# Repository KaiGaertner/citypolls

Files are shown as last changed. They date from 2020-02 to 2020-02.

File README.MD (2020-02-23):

# Project: Help yourself city

Creating a real life usable voting plattform for local issues. Based on a Raspberry Pi Zero WH, an UMTS module, a powerbank and self made casing out of acryl, it can be put nearly anywhere to vote on a given topic by up- or downvoting.

## Server implemenation
The project uses a simple MySQL database to store the votes over a predefined period of time and can present them via a website. A running prototype could be found at: cit

## UrbanAnt

### Casing
The casing consists of laser cut acryl and 3D printed parts, some buttons, cables and LEDs for the interior. It provides enough space for the Raspberry Pi Zero WH, the UMTS module and a battery.
The case consists of laser cut and 3D-printed parts. The necessary files are included in the folders named correspondingly. 

## Programming
The control programm is written for Python 3 running on Raspbian Buster on the Rasperry Pi. All functionalities can be found in the *box.py* which runs as a service after powering up the device.
The votes are stored locally in a sqlite database and can be commited to the MySQL server in e predefined interval. The only additional dependencies for the programm are the [mysql-connector-python](https://pypi.org/project/mysql-connector-python/) package and [RPi.GPIO](https://pypi.org/project/RPi.GPIO/) which can be installed using:
```bash
pip3 install mysql-connector-python RPi.GPIO
```
For the voting a delay can be set to avoid abusive usage by voting rapidly.

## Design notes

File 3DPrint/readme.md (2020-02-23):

In this folder you can find all the 3D-printed parts for the UrbanAnt device. 
Upvote and Downvote buttons are the same, just be careful when mounting them.

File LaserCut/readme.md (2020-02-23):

In this folder you can find all the lasercut parts for the UrbanAnt device. Every part is stored in a separate pdf file. 
The files are A4-sized, so if you want to use some other technique instead of lasercutting, you can just print them out with a regular printer.

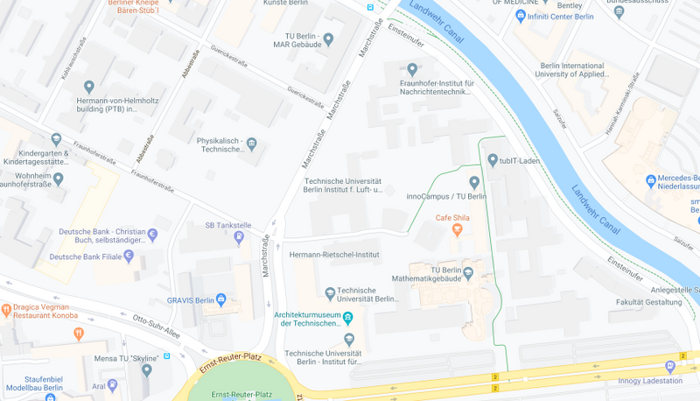
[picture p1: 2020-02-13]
website/images/try-p-800.png

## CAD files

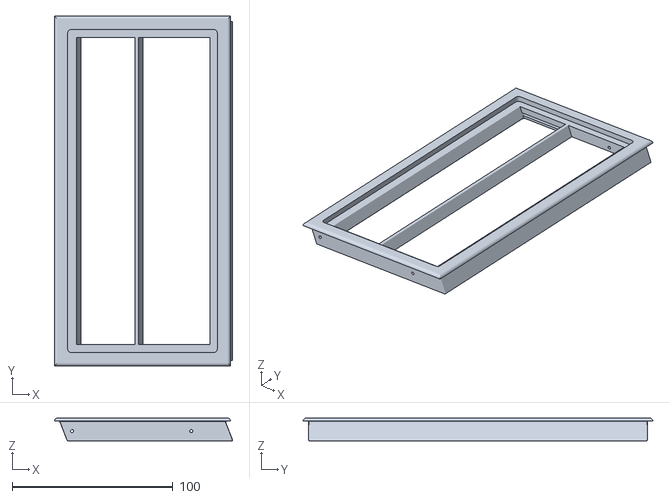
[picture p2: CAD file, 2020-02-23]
3DPrint/Frame_1pc.stl
111.0 x 218.0 x 14.3

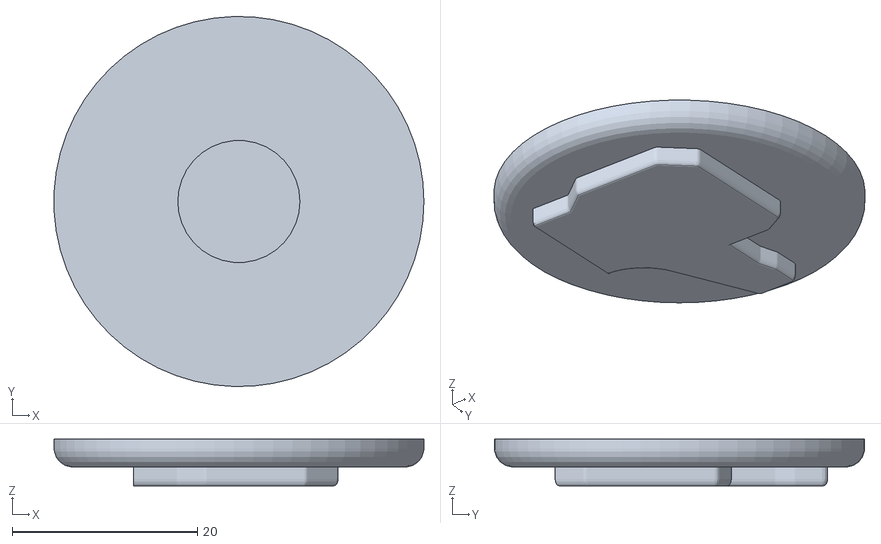
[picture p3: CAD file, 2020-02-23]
3DPrint/VoteButton_2pcs.stl
40.0 x 40.0 x 5.04

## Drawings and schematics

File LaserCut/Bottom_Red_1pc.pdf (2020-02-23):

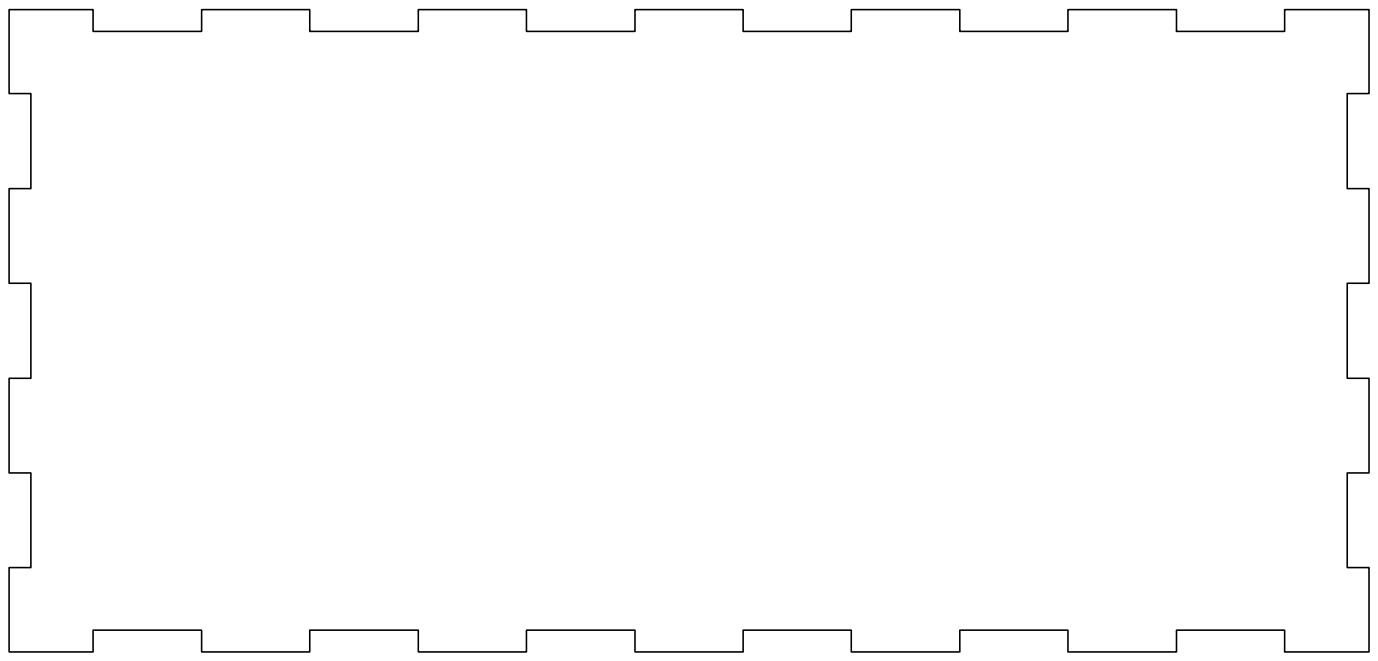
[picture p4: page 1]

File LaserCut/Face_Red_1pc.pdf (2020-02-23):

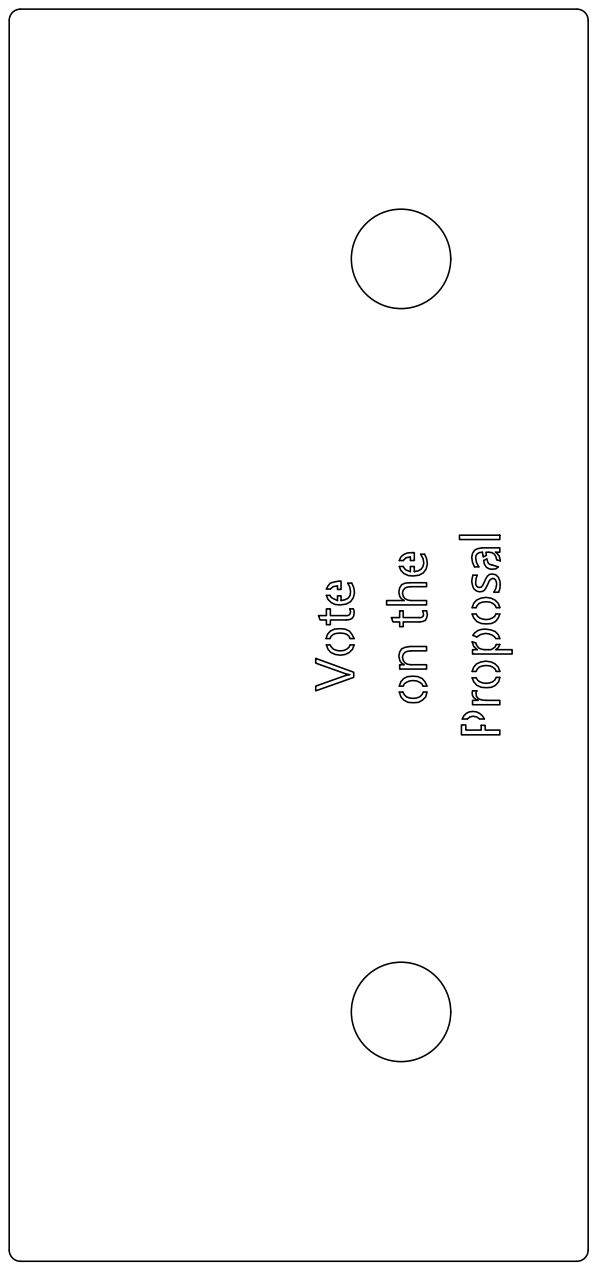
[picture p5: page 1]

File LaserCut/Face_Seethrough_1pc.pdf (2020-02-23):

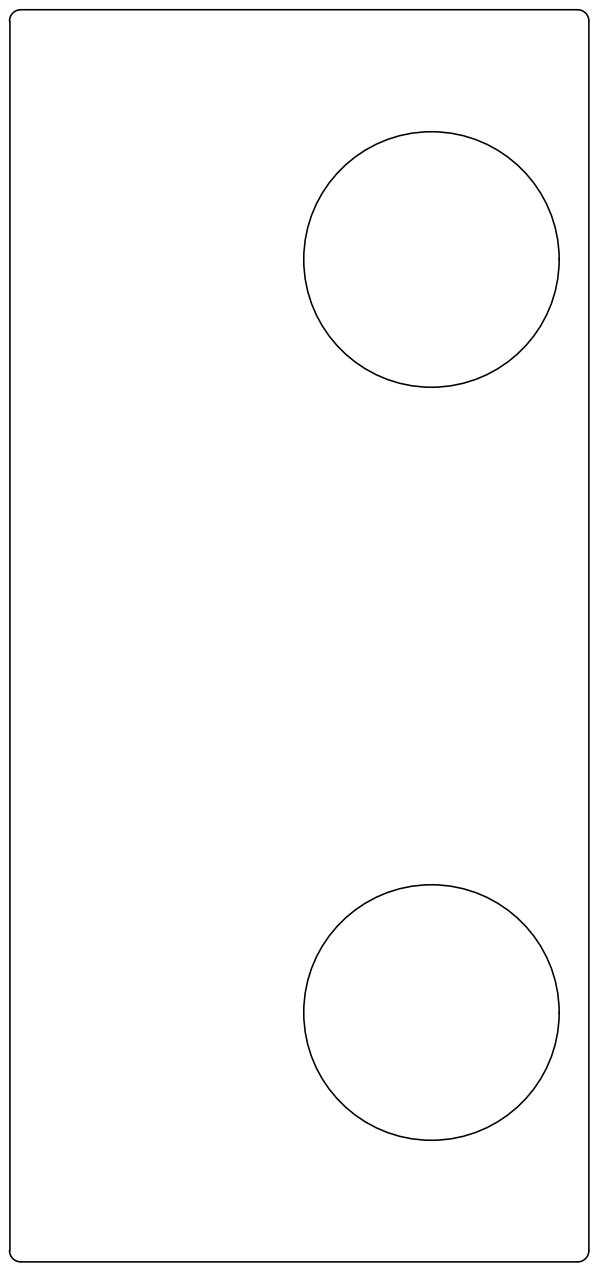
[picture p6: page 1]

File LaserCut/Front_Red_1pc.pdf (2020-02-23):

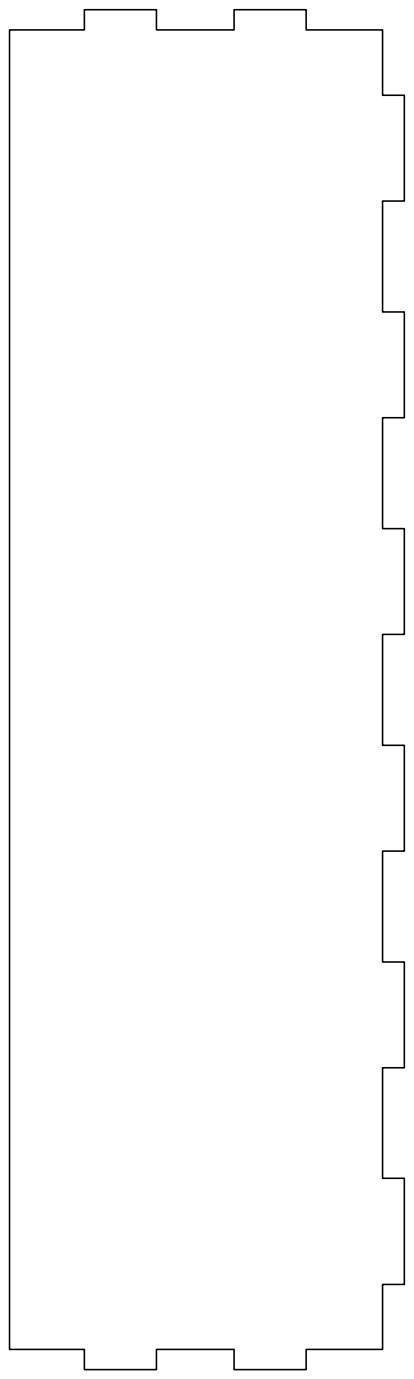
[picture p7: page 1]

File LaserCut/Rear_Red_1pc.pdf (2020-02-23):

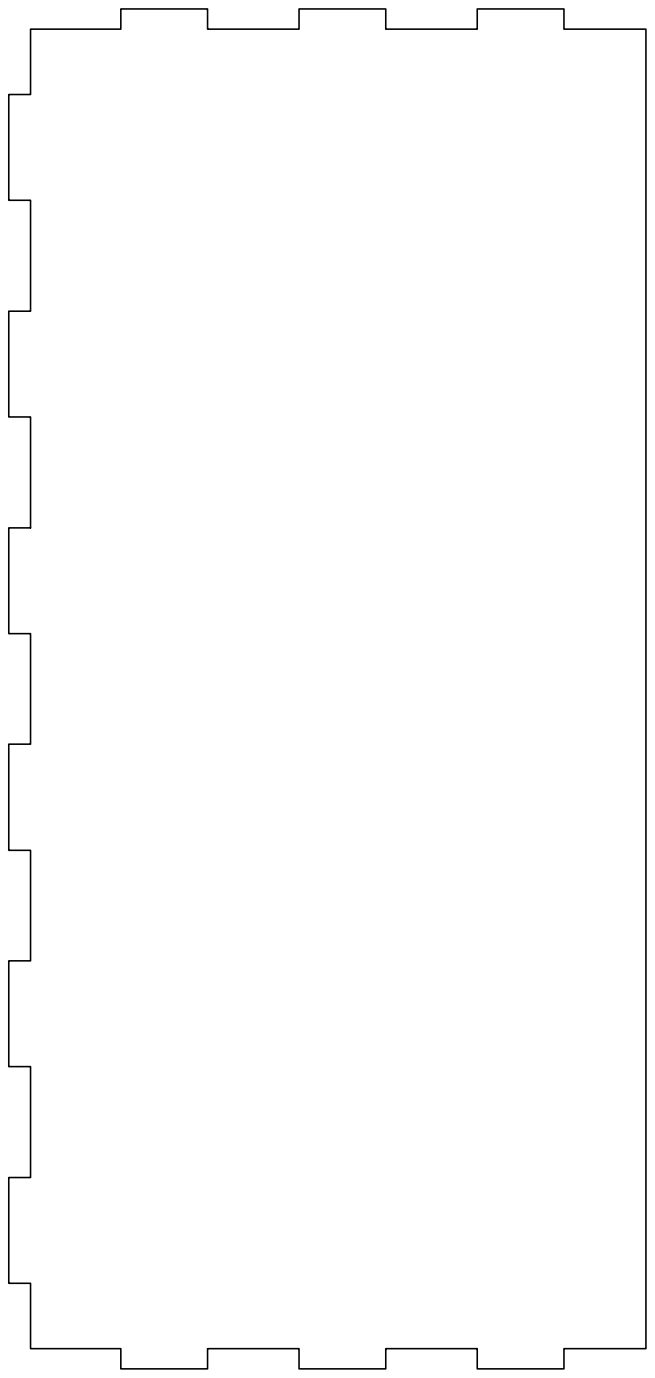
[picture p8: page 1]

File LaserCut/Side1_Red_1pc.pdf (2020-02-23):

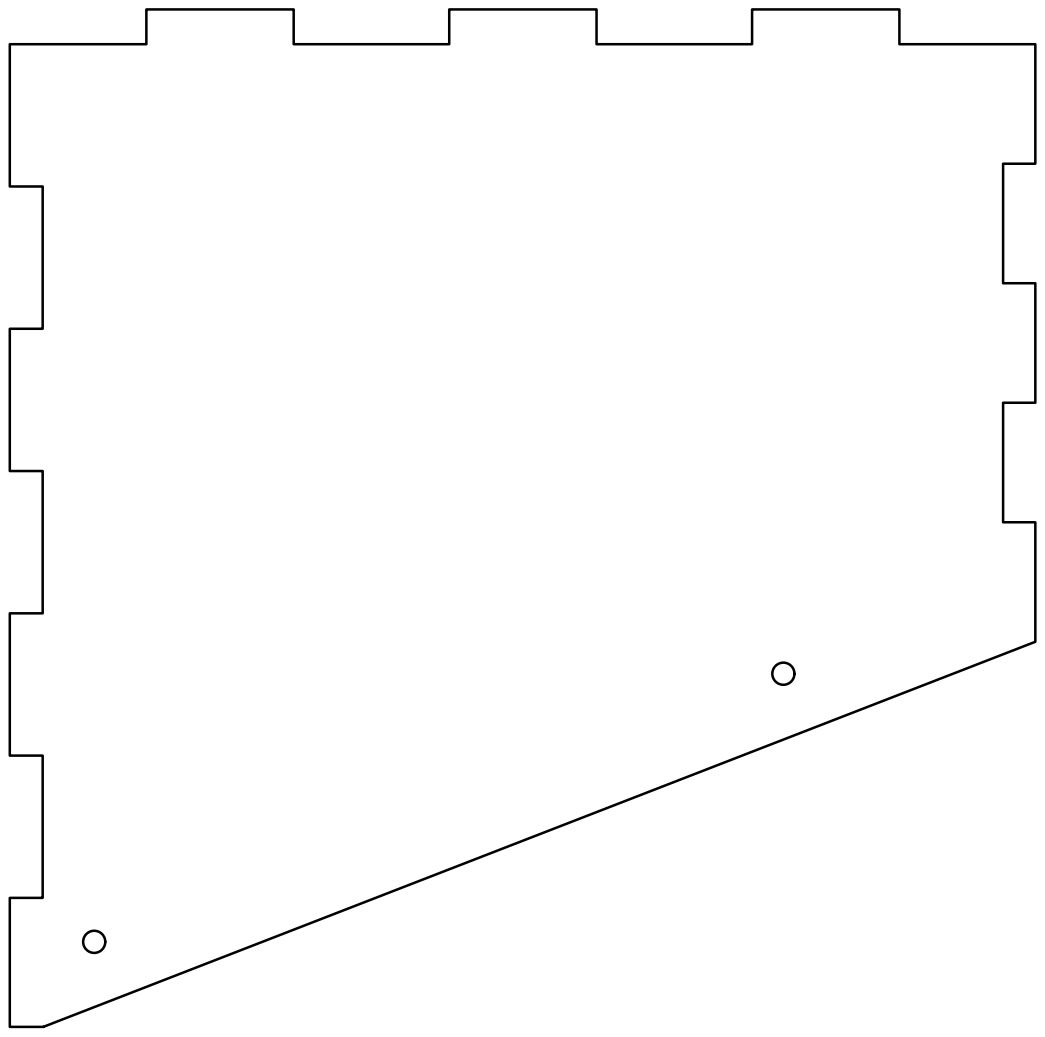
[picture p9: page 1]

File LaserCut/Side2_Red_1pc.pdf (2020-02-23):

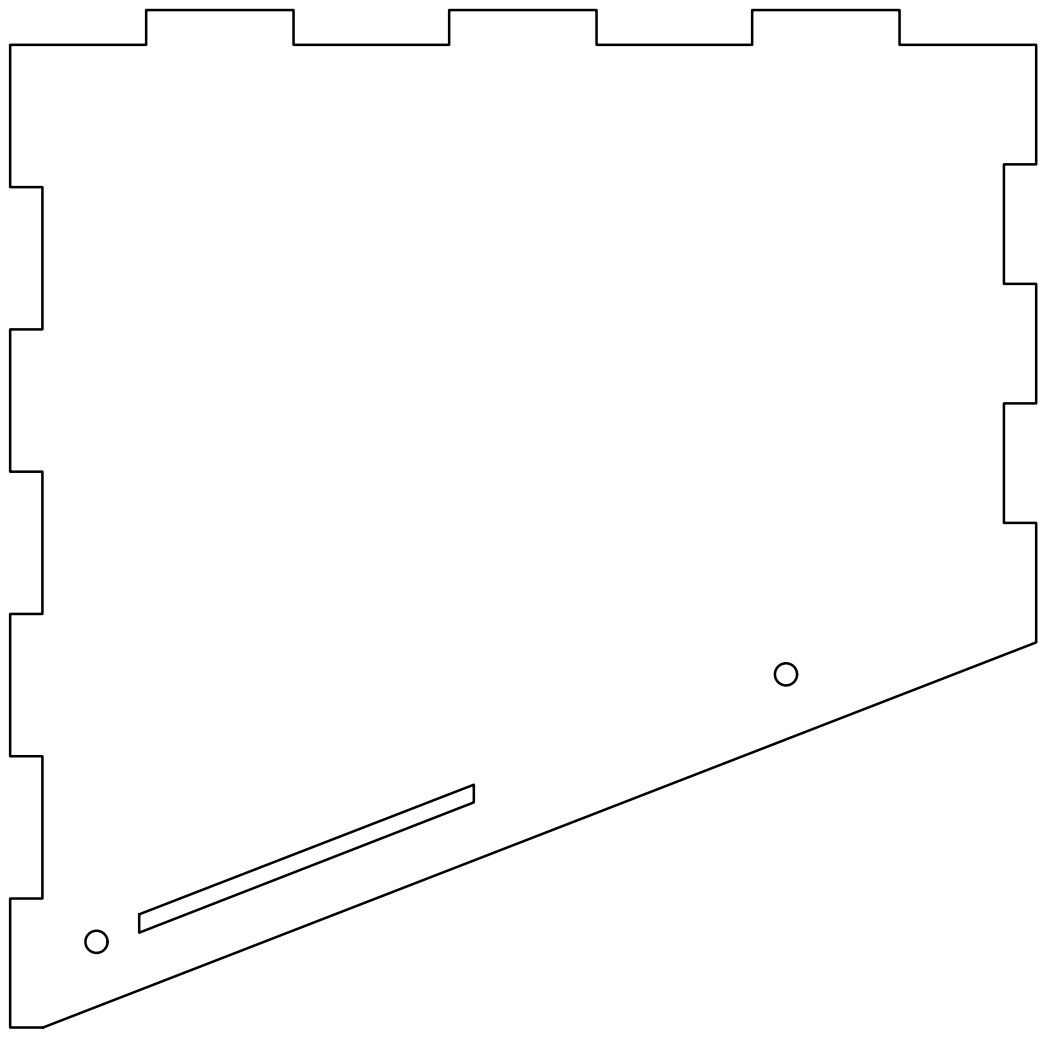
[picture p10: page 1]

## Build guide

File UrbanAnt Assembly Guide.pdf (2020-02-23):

UrbanAnt Assembly Guide

### 1. Gluing the box

Parts needed:
Bottom_Red
Front_Red
Rear_Red
Side1_Red
Side2_Red

Additional material:
Paper tape
Epoxy glue

Instructions:
Put the involved parts together. Use paper tape from the outside to make it stay steadily. Apply (two-component epoxy resin) glue from the inside along the gaps. After the glue has cured, the paper tape can be removed.

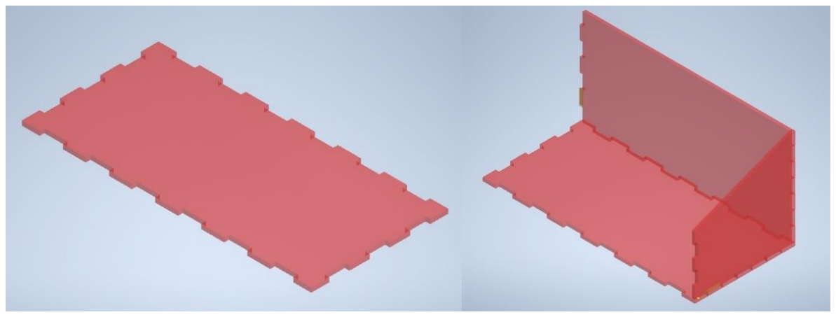
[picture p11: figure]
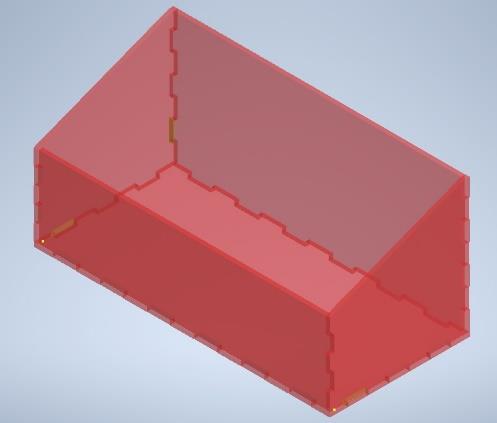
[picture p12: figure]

### 2. Adding brass inserts

Parts needed:
Frame

Additional material and tools: Drill 2.5-2.7mm
Soldering iron
M2 Brass inserts x4

Instructions:
Predrill all four holes on the sides of the frame. Insert the brass inserts using soldering iron.

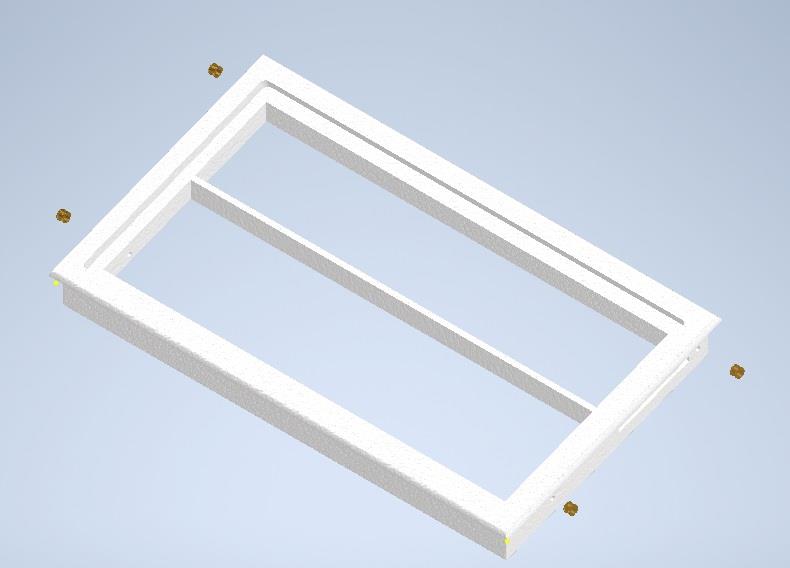
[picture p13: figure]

### 3. Adding the covers

Parts needed:
Frame
Face_Red

Additional material and tools: Epoxy glue

Instructions:
Place and glue the face plate into the frame.

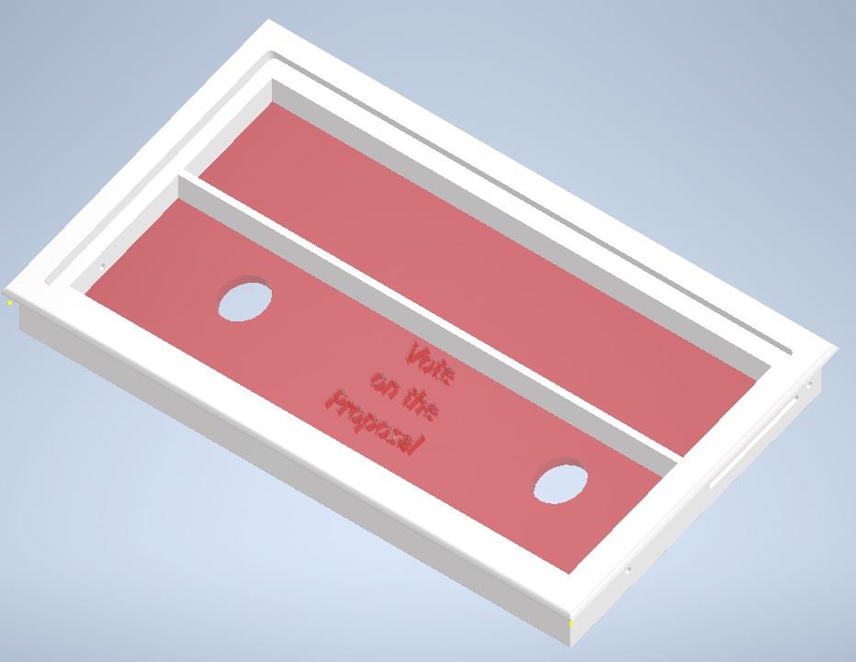
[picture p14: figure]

### 4. Gluing the buttons

Parts needed:
Non-latching buttons x2
VoteButton x2

Additional material and tools: Epoxy glue

Instructions:
Glue the 3D-printed button covers on the buttons. You might need to press them together until the glue cures.

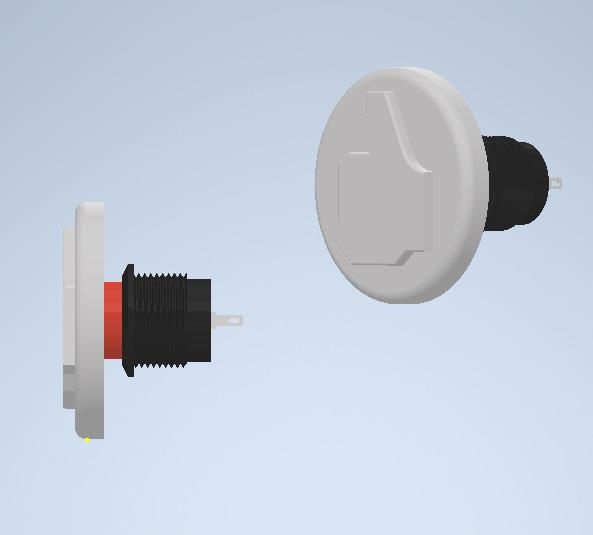
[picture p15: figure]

### 5. Putting UrbanAnt together

Parts needed:
The previous assemblies
Internal electronics assembled based on the GitHub Wiki Front_Seethrough

Additional material and tools:
Epoxy glue
M2 screws x4

Instructions:
Place and mount the buttons. Glue the see-through face on the box, and sink the face assembly into the box. You can secure it with the four screws from the sides. A paper with the message can be added using the slot on the side of the box.

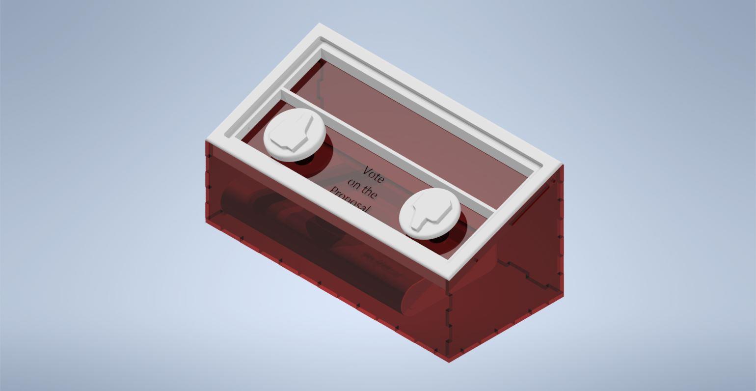
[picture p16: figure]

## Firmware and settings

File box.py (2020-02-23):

import sqlite3, random, time
import mysql.connector
import RPi.GPIO as GPIO
from sqlite3 import Error
import threading


box_id = 1
vote_id = 2

### local counting
def count_vote(conn, vote):
	try:
		c = conn.cursor()
		if vote:
			c.execute(""" UPDATE polls SET yes = yes + 1 WHERE poll_id=""" + str(vote_id))
		else:
			c.execute(""" UPDATE polls SET no = no + 1 WHERE poll_id="""+str(vote_id))
		c.execute(""" UPDATE polls SET last_update = datetime('now') """)
	except Error as e:
		print(e)
	finally:
		conn.commit()


def init_vote(conn):
	c = conn.cursor()
	try:
		c.execute(" INSERT INTO polls (box_id, poll_id, yes, no, last_update) VALUES( " + str(box_id)+"," + str(vote_id)+",0,0,datetime('now')); ")
	except Error as e:
		print(e)

def connect_db():

	""" create a database connection to a SQLite database """
	conn = None
	try:
		conn = sqlite3.connect('local_polls.db')
		try:
			c = conn.cursor()
			c.execute(""" CREATE TABLE IF NOT EXISTS polls (
											box_id integer, poll_id integer PRIMARY KEY,
											yes integer, no integer, last_update datetime
										); """)
			#init_vote(c)
		except Error as e:
			print(e)

	except Error as e:
		print(e)
	finally:
		if conn:
			conn.commit()
			#conn.close()
			return conn




# remote counting
def get_votes():
	""" create a database connection to a SQLite database """
	conn = None
	results = []
	try:
		conn = sqlite3.connect('local_polls.db')
		c = conn.cursor()
		try:
			c.execute(""" SELECT yes, no FROM polls WHERE box_id="""+str(box_id)+""" AND poll_id="""+str(vote_id))
			for row in c.fetchall():
				results.append(row[0])
				results.append(row[1])
				print ("GET VOTES: [BOX-ID]: " + str(box_id) + " [VOTE-ID]: "+ str(vote_id)+" [YES]: "+ str(row[0])+" [NO]: "+str(row[1]))

		except Error as e:
			print(e)

	except Error as e:
		print(e)
	finally:
		if conn:
			conn.close()
	return results


def push_votes(votes):
	if len(votes) > 0:
		try:
			cnx = mysql.connector.connect(user='citypolls', password='Hml8h30#',
										  host='kaigaertner.de',port=3306,
										  database='citypolls')
			mycursor = cnx.cursor()
			sql = " INSERT INTO boxes (boxid, pollid, yes, no, creation) VALUES (%s, %s, %s, %s, NOW()) "
			val = (box_id,vote_id,votes[0], votes[1])
			mycursor.execute(sql, val)
			cnx.commit()
			print(mycursor.rowcount, "record inserted.")
		except mysql.connector.Error as err:
			if err.errno == errorcode.ER_ACCESS_DENIED_ERROR:
				print("Something is wrong with your user name or password")
			elif err.errno == errorcode.ER_BAD_DB_ERROR:
				print("Database does not exist")
			else:
				print(err)
		else:
			cnx.close()

def sync_votes():
	votes = []
	votes = get_votes()
	push_votes(votes)


### main programm ###

# database connection
conn = connect_db()

#button = random.choice((True, False))
#count_vote(conn, button)
#c = conn.cursor()
#get_votes(c)
init_vote(conn)

GPIO.setwarnings(False) # Ignore warning for now
GPIO.setmode(GPIO.BOARD) # Use physical pin numbering
GPIO.setup(10, GPIO.IN, pull_up_down=GPIO.PUD_DOWN) # Set pin 10 to be an input pin and set initial value to be pulle$
GPIO.setup(12, GPIO.IN, pull_up_down=GPIO.PUD_DOWN)

# use LEDs as visual feedback
GPIO.setup(38, GPIO.OUT)
GPIO.setup(40, GPIO.OUT)

clock = 1
while True: # Run forever
	if GPIO.input(10) == GPIO.LOW:
		print("Button YES was pushed!")
		GPIO.output(38, GPIO.HIGH)
		count_vote(conn, True)
		time.sleep(.1)
		conn.commit()
		#t = threading.Thread(name='child procs', target=sync_votes)
		#t.start()
		sync_votes()
		GPIO.output(38, GPIO.LOW)
	if GPIO.input(12) == GPIO.LOW:
		print("Button NO was pushed!")
		GPIO.output(40, GPIO.HIGH)
		count_vote(conn, False)
		time.sleep(.1)
		conn.commit()
		#t = threading.Thread(name='child procs', target=sync_votes)
		#t.start()
		sync_votes()
		GPIO.output(40, GPIO.LOW)
		# if ((clock % 5) == 0):
		#conn.commit()
		# if ((clock % 5) == 0):
		# t = threading.Thread(name='child procs', target=sync_votes)
		# t.start()
		#sync_votes()
	clock = clock+1
	time.sleep(.1)

conn.close()

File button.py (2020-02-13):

import RPi.GPIO as GPIO # Import Raspberry Pi GPIO library

def button_callback_yes(channel):
    print("Button YES was pushed!")
def button_callback_no(channel):
    print("Button NO was pushed!")

GPIO.setwarnings(False) # Ignore warning for now
GPIO.setmode(GPIO.BOARD) # Use physical pin numbering
GPIO.setup(10, GPIO.IN, pull_up_down=GPIO.PUD_DOWN) # Set pin 10 to be an input pin and set initial value to be pulled low (off)
GPIO.setup(12, GPIO.IN, pull_up_down=GPIO.PUD_DOWN)

GPIO.add_event_detect(10,GPIO.RISING,callback=button_callback_yes) # Setup event on pin 10 rising edge
GPIO.add_event_detect(12,GPIO.RISING,callback=button_callback_no) 

message = input("Press enter to quit\n\n") # Run until someone presses enter

GPIO.cleanup() # Clean up

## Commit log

2020-02-22 LEDs added
2020-02-23 Add files via upload
    LaserCutter files added
2020-02-23 Add files via upload
    3D-print files added
    [Frame_1pc.stl, VoteButton_2pcs.stl]
2020-02-23 Add files via upload
    Hardware assembly guide
